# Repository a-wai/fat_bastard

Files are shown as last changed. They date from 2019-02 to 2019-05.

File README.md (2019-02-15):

Copyright 2019, Arnaud Ferraris.

This documentation describes Open Hardware and is licensed under the
CERN OHL v.1.2.

You may redistribute and modify this documentation under the terms of the
CERN OHL v.1.2. (http://ohwr.org/cernohl).This documentation is distributed
WITHOUT ANY EXPRESS OR IMPLIED WARRANTY, INCLUDING OF MERCHANTABILITY, 
SATISFACTORY QUALITY AND FITNESS FOR A PARTICULAR PURPOSE.

Please see the CERN OHL v.1.2 for applicable conditions.

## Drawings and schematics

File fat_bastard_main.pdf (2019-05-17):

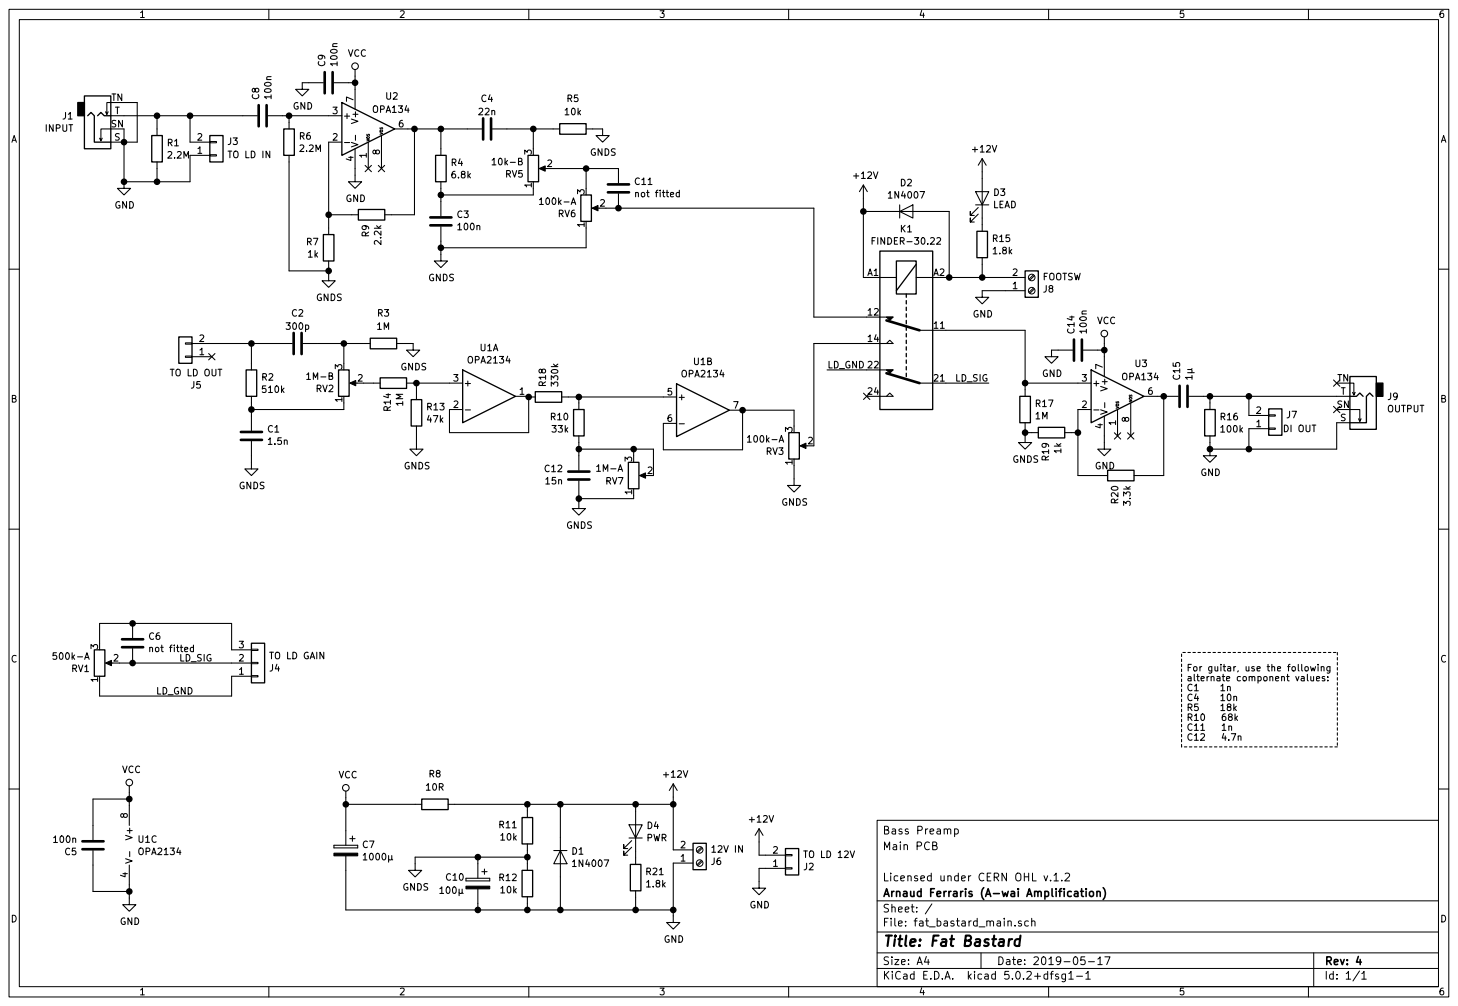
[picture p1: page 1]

For guitar, use the following
alternate component values: C1 1n C4 10n R5 18k R10 68k C11 1n C12 4.7n

Bass Preamp
File: fat_bastard_main.sch Sheet: / Arnaud Ferraris (A-wai Amplification) Licensed under CERN OHL v.1.2 Main PCB

Id: 1/1 Title: Fat Bastard

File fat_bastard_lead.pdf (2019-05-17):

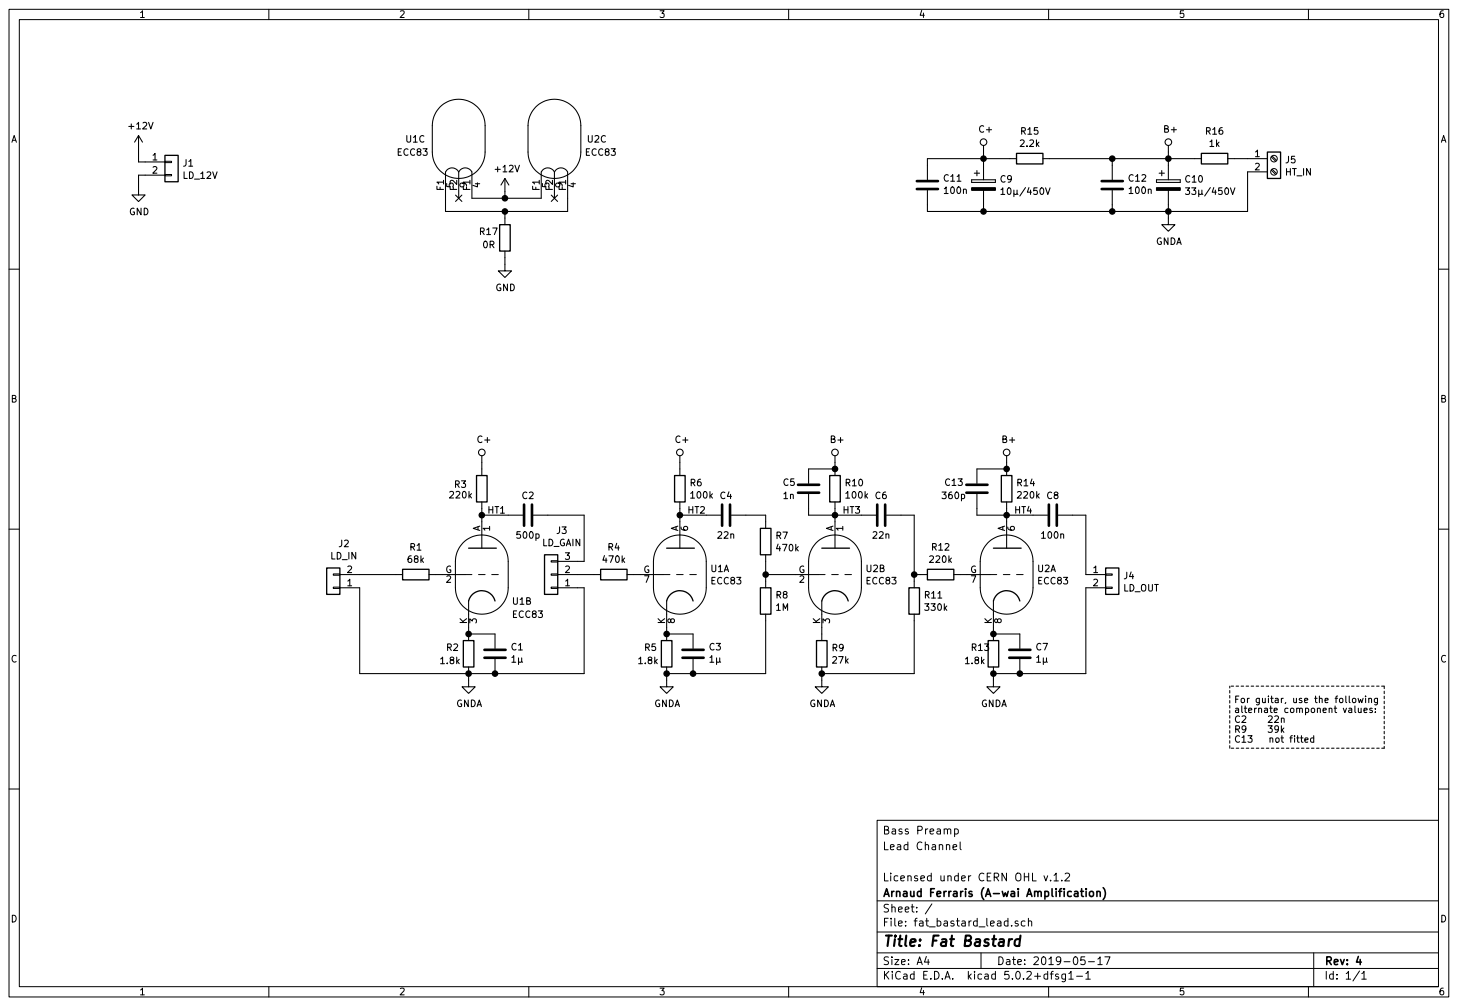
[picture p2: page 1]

Lead Channel Bass Preamp A

For guitar, use the following
alternate component values: C2 22n R9 39k C13 not fitted

File: fat_bastard_lead.sch Sheet: / Arnaud Ferraris (A-wai Amplification) Licensed under CERN OHL v.1.2

Id: 1/1 Title: Fat Bastard

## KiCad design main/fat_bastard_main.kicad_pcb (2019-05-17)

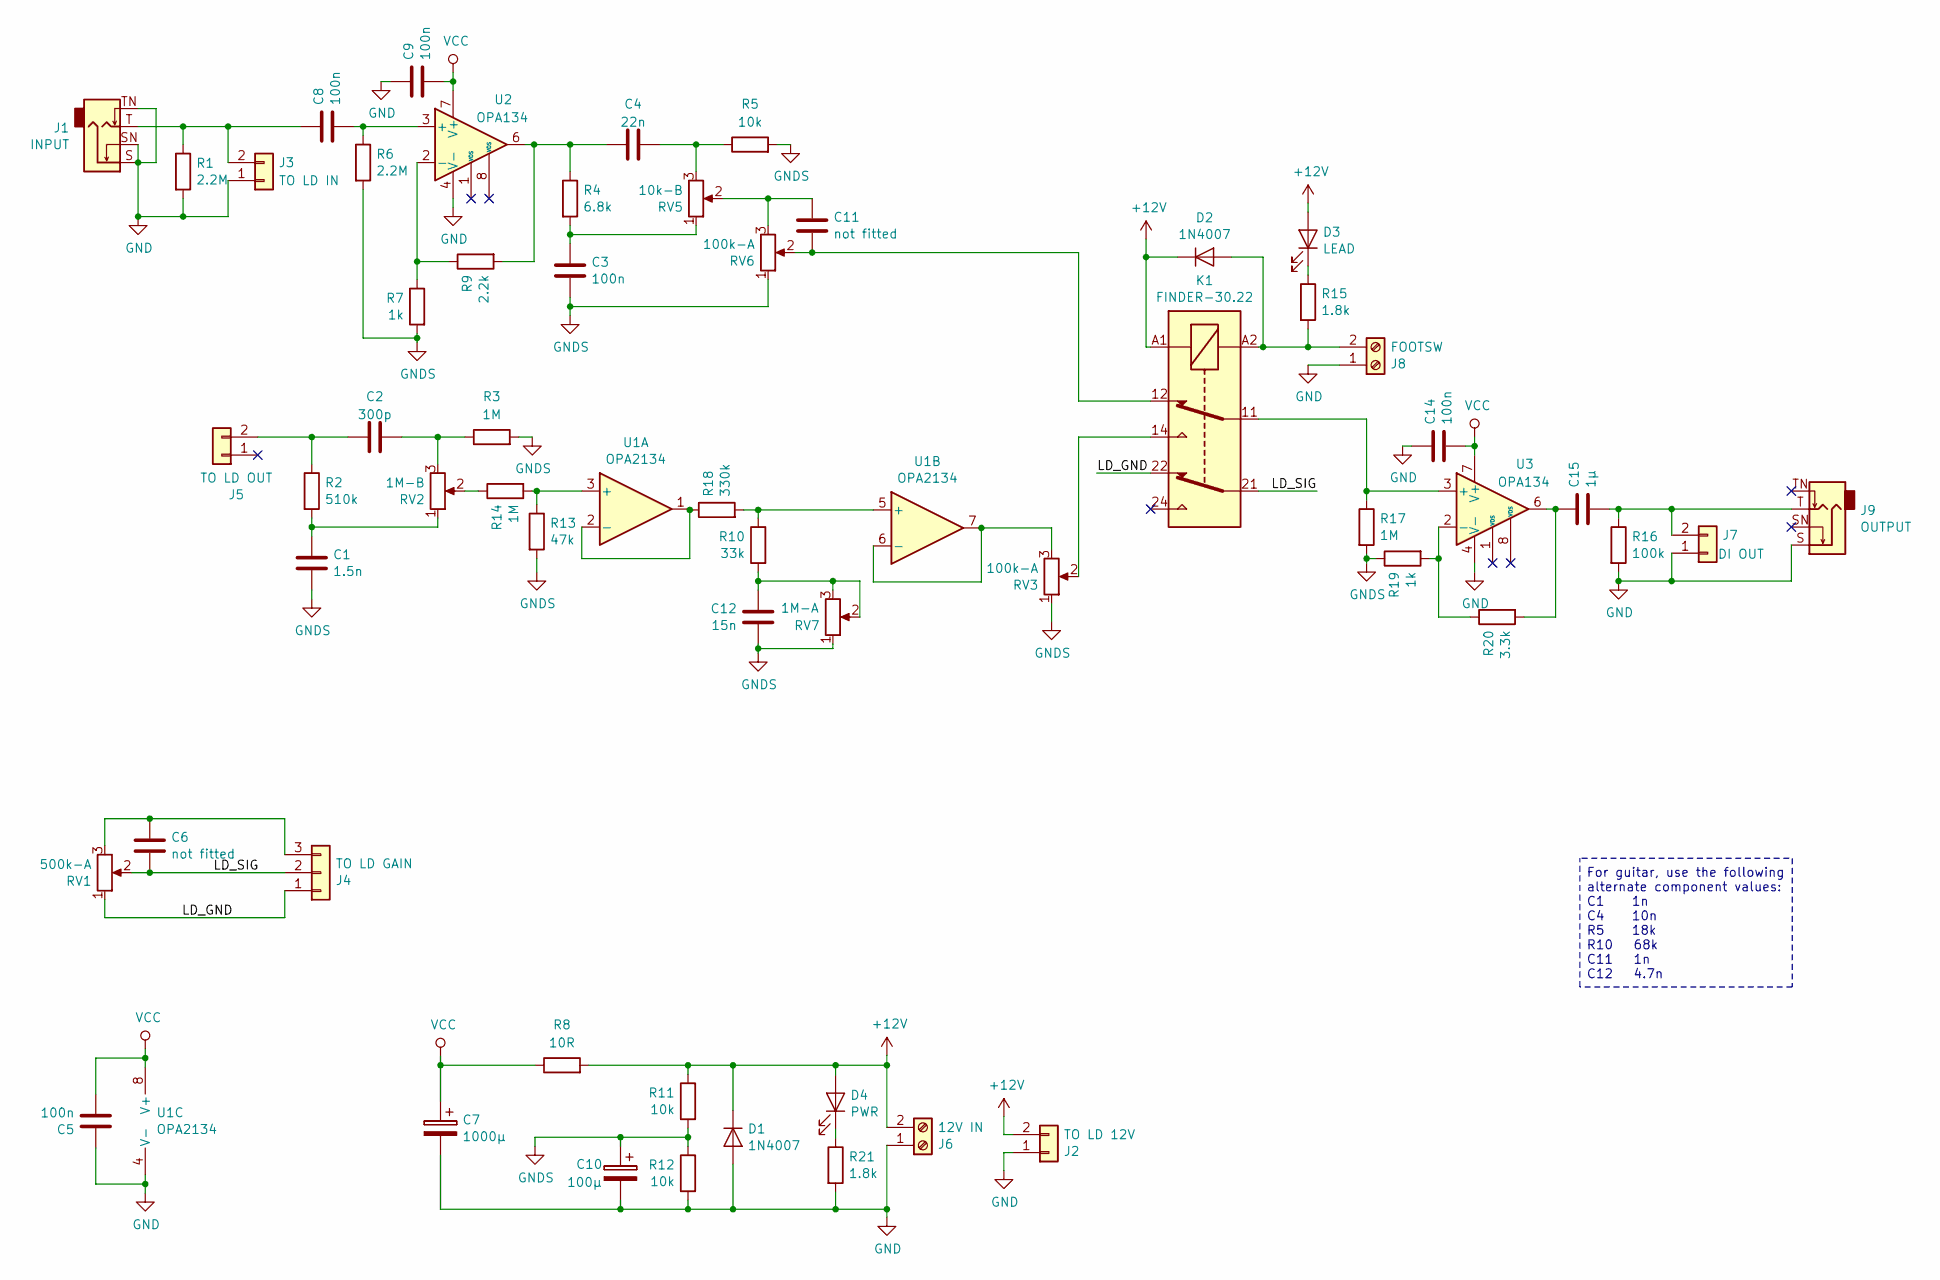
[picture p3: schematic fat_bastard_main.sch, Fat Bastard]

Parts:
C1: 1.5n; C_Rect_L7.2mm_W3.0mm_P5.00mm_FKS2_FKP2_MKS2_MKP2; MPN MKP2
C2: 300p; C_Disc_D10.5mm_W5.0mm_P5.00mm
C3, C5, C8, C9, C14: 100n; C_Rect_L7.2mm_W3.0mm_P5.00mm_FKS2_FKP2_MKS2_MKP2; MPN MKS2D031001A00KSSD
C4: 22n; C_Rect_L7.2mm_W3.0mm_P5.00mm_FKS2_FKP2_MKS2_MKP2; MPN MKS2C022201A00KSSD
C6, C11: not fitted; C_Disc_D10.5mm_W5.0mm_P5.00mm
C7: 1000µ; CP_Radial_D10.0mm_P5.00mm
C10: 100µ; CP_Radial_D8.0mm_P3.80mm; MPN FW
C12: 15n; C_Rect_L7.2mm_W3.0mm_P5.00mm_FKS2_FKP2_MKS2_MKP2; MPN MKS2D021001A00KSSD
C15: 1µ; C_Rect_L7.2mm_W4.5mm_P5.00mm_FKS2_FKP2_MKS2_MKP2; MPN MKS2C041001F00KSSD
D1, D2: 1N4007; D_DO-41_SOD81_P7.62mm_Horizontal
D3: LEAD; LED_D3.0mm_Horizontal_O6.35mm_Z10.0mm
D4: PWR; LED_D3.0mm_Horizontal_O3.81mm_Z2.0mm
J1: INPUT; Jack_3.5mm_Neutrik_NMJ6HCD2_Horizontal; MPN NMJ4HCD2
J2: TO LD 12V; PinHeader_1x02_P2.54mm_Vertical
J3: TO LD IN; PinHeader_1x02_P2.54mm_Vertical
J4: TO LD GAIN; PinHeader_1x03_P2.54mm_Vertical
J5: TO LD OUT; PinHeader_1x02_P2.54mm_Vertical
J6: 12V IN; TerminalBlock_RND_205-00001_1x02_P5.00mm_Horizontal; MPN 691102710002
J7: DI OUT; PinHeader_1x02_P2.54mm_Vertical
J8: FOOTSW; TerminalBlock_RND_205-00001_1x02_P5.00mm_Horizontal; MPN 691102710002
J9: OUTPUT; Jack_3.5mm_Neutrik_NMJ6HCD2_Horizontal; MPN NMJ4HCD2
K1: FINDER-30.22; Relay_DPDT_Finder_30.22; MPN G5V-2
R1, R6: 2.2M; R_Axial_DIN0309_L9.0mm_D3.2mm_P12.70mm_Horizontal
R2: 510k; R_Axial_DIN0309_L9.0mm_D3.2mm_P12.70mm_Horizontal
R3, R14, R17: 1M; R_Axial_DIN0309_L9.0mm_D3.2mm_P12.70mm_Horizontal
R4: 6.8k; R_Axial_DIN0309_L9.0mm_D3.2mm_P12.70mm_Horizontal
R5, R11, R12: 10k; R_Axial_DIN0309_L9.0mm_D3.2mm_P12.70mm_Horizontal
R7, R19: 1k; R_Axial_DIN0309_L9.0mm_D3.2mm_P12.70mm_Horizontal
R8: 10R; R_Axial_DIN0309_L9.0mm_D3.2mm_P12.70mm_Horizontal
R9: 2.2k; R_Axial_DIN0309_L9.0mm_D3.2mm_P12.70mm_Horizontal
R10: 33k; R_Axial_DIN0309_L9.0mm_D3.2mm_P12.70mm_Horizontal
R13: 47k; R_Axial_DIN0309_L9.0mm_D3.2mm_P12.70mm_Horizontal
R15, R21: 1.8k; R_Axial_DIN0309_L9.0mm_D3.2mm_P12.70mm_Horizontal
R16: 100k; R_Axial_DIN0309_L9.0mm_D3.2mm_P12.70mm_Horizontal
R18: 330k; R_Axial_DIN0309_L9.0mm_D3.2mm_P12.70mm_Horizontal
R20: 3.3k; R_Axial_DIN0309_L9.0mm_D3.2mm_P12.70mm_Horizontal
RV1: 500k-A; Potentiometer_Alps_RK163_Single_Horizontal
RV2: 1M-B; Potentiometer_Alps_RK163_Single_Horizontal
RV3, RV6: 100k-A; Potentiometer_Alps_RK163_Single_Horizontal
RV5: 10k-B; Potentiometer_Alps_RK163_Single_Horizontal
RV7: 1M-A; Potentiometer_Alps_RK163_Single_Horizontal
U1: OPA2134; DIP-8_W7.62mm_Socket_LongPads; MPN OPA2134PA
U2, U3: OPA134; DIP-8_W7.62mm_Socket_LongPads; MPN OPA134PA

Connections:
+12V: D1.1 (K), D2.1 (K), D3.2 (A), D4.2 (A), J2.2, J6.2, K1.A1, R8.2, R11.1
/LD_GND: J4.1, K1.22, RV1.1
/LD_SIG: C6.1, J4.2, K1.21, RV1.2
GND: C5.2, C7.2, C9.2, C10.2, C14.2, D1.2 (A), J1.S, J1.SN, J1.TN, J2.1, J3.1, J6.1, J7.1, J8.1, J9.S, R1.2, R12.2, R16.2, R21.2, U1.4 (V-), U2.4 (V-), U3.4 (V-)
GNDS: C1.1, C3.1, C10.1, C12.1, R3.2, R5.2, R6.2, R7.2, R11.2, R12.1, R13.2, R17.2, R19.1, RV3.1, RV6.1, RV7.1
unnamed: C1.2, R2.2, RV2.1
unnamed: C2.1, J5.2, R2.1
unnamed: C2.2, R3.1, RV2.3
unnamed: C3.2, R4.2, RV5.1
unnamed: C4.1, R4.1, R9.2, U2.6
unnamed: C4.2, R5.1, RV5.3
unnamed: C6.2, J4.3, RV1.3
unnamed: C8.1, R6.1, U2.3 (+)
unnamed: C8.2, J1.T, J3.2, R1.1
unnamed: C11.1, K1.12, RV6.2
unnamed: C11.2, RV5.2, RV6.3
unnamed: C12.2, R10.2, RV7.2, RV7.3
unnamed: C15.1, J7.2, J9.T, R16.1
unnamed: C15.2, R20.2, U3.6
unnamed: D2.2 (A), J8.2, K1.A2, R15.2
unnamed: D3.1 (K), R15.1
unnamed: D4.1 (K), R21.1
unnamed: K1.11, R17.1, U3.3 (+)
unnamed: K1.14, RV3.2
unnamed: R7.1, R9.1, U2.2 (-)
unnamed: R10.1, R18.2, U1.5 (+)
unnamed: R13.1, R14.2, U1.3 (+)
unnamed: R14.1, RV2.2
unnamed: R18.1, U1.1, U1.2 (-)
unnamed: R19.2, R20.1, U3.2 (-)
unnamed: RV3.3, U1.6 (-), U1.7
VCC: C5.1, C7.1, C9.1, C14.1, R8.1, U1.8 (V+), U2.7 (V+), U3.7 (V+)

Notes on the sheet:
For guitar, use the following alternate component values: C1 1n C4 10n R5 18k R10 68k C11 1n C12 4.7n

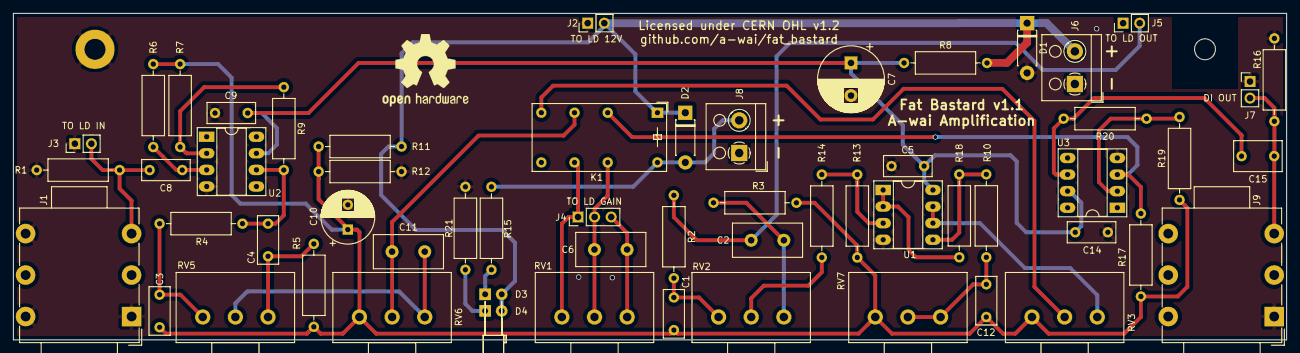
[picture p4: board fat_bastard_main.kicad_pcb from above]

Board: 2 copper layers, 195.0 x 50.0 mm, 60 parts (0 on the bottom side), 32 nets.

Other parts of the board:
DRILL: MountingHole_3.2mm_M3
DRILL#2: MountingHole_3.2mm_M3

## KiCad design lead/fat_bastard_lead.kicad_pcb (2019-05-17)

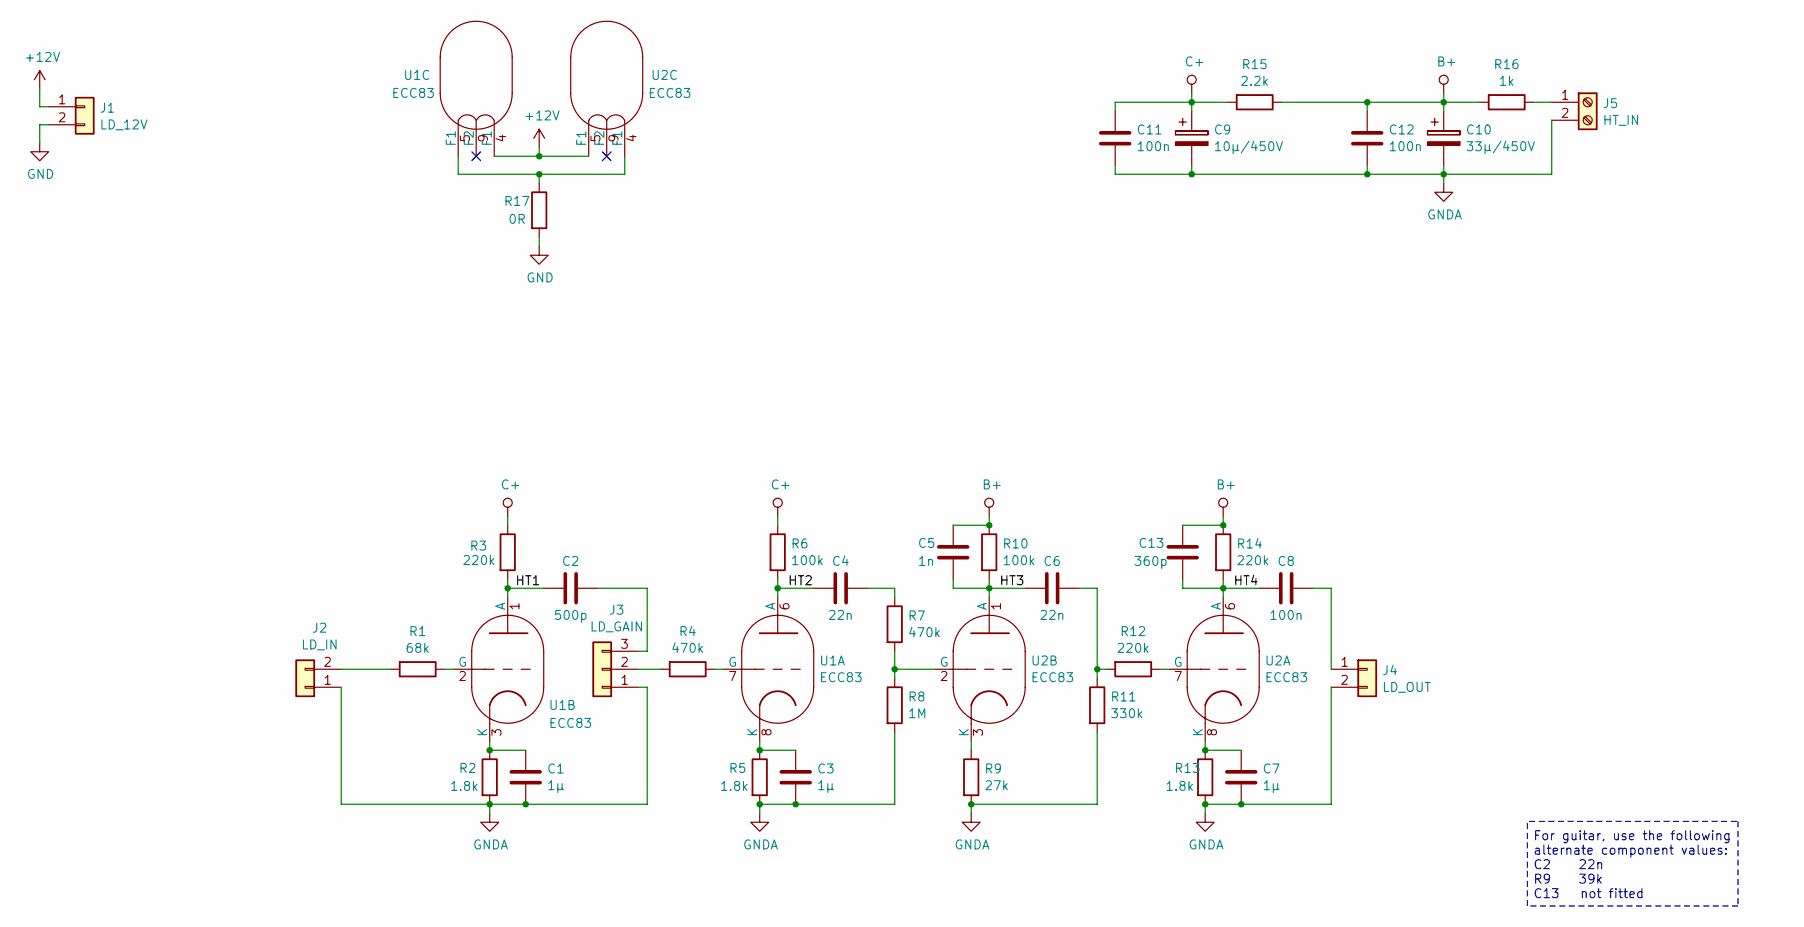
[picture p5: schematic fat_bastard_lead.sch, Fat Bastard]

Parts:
C1, C3, C7: 1µ; C_Rect_L7.2mm_W4.5mm_P5.00mm_FKS2_FKP2_MKS2_MKP2
C2: 500p; C_Disc_D11.0mm_W5.0mm_P5.00mm
C4, C6: 22n; C_Rect_L13.0mm_W4.0mm_P10.00mm_FKS3_FKP3_MKS4
C5: 1n; C_Rect_L13.0mm_W4.0mm_P10.00mm_FKS3_FKP3_MKS4
C8, C11, C12: 100n; C_Rect_L19.0mm_W6.0mm_P15.00mm_MKS4
C9: 10µ/450V; CP_Radial_D13.0mm_P5.00mm
C10: 33µ/450V; CP_Radial_D16.0mm_P7.50mm
C13: 360p; C_Disc_D11.0mm_W5.0mm_P5.00mm
J1: LD_12V; PinHeader_1x02_P2.54mm_Horizontal
J2: LD_IN; PinHeader_1x02_P2.54mm_Vertical
J3: LD_GAIN; PinHeader_1x03_P2.54mm_Vertical
J4: LD_OUT; PinHeader_1x02_P2.54mm_Horizontal
J5: HT_IN; TerminalBlock_RND_205-00001_1x02_P5.00mm_Horizontal
R1: 68k; R_Axial_DIN0309_L9.0mm_D3.2mm_P12.70mm_Horizontal
R2, R5, R13: 1.8k; R_Axial_DIN0309_L9.0mm_D3.2mm_P12.70mm_Horizontal
R3, R12, R14: 220k; R_Axial_DIN0309_L9.0mm_D3.2mm_P12.70mm_Horizontal
R4, R7: 470k; R_Axial_DIN0309_L9.0mm_D3.2mm_P12.70mm_Horizontal
R6, R10: 100k; R_Axial_DIN0309_L9.0mm_D3.2mm_P12.70mm_Horizontal
R8: 1M; R_Axial_DIN0309_L9.0mm_D3.2mm_P12.70mm_Horizontal
R9: 27k; R_Axial_DIN0309_L9.0mm_D3.2mm_P12.70mm_Horizontal
R11: 330k; R_Axial_DIN0309_L9.0mm_D3.2mm_P12.70mm_Horizontal
R15: 2.2k; R_Axial_DIN0309_L9.0mm_D3.2mm_P12.70mm_Horizontal
R16: 1k; R_Axial_DIN0309_L9.0mm_D3.2mm_P12.70mm_Horizontal
R17: 0R; SolderJumper-2_P1.3mm_Bridged2Bar_Pad1.0x1.5mm
U1, U2: ECC83; Valve_Noval-B9A_Belton-VT9-PT_Socket

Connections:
+12V: J1.1, U1.4 (F1), U2.5 (F1)
/HT1: C2.2, R3.2, U1.1 (A)
/HT2: C4.2, R6.2, U1.6 (A)
/HT3: C5.2, C6.2, R10.2, U2.1 (A)
/HT4: C8.2, C13.2, R14.2, U2.6 (A)
B+: C5.1, C10.1, C12.2, C13.1, R10.1, R14.1, R15.1, R16.2
C+: C9.1, C11.2, R3.1, R6.1, R15.2
GND: J1.2, R17.2
GNDA: C1.1, C3.1, C7.1, C9.2, C10.2, C11.1, C12.1, J2.1, J3.1, J4.2, J5.2, R2.2, R5.2, R8.2, R9.2, R11.2, R13.2
unnamed: C1.2, R2.1, U1.3 (K)
unnamed: C2.1, J3.3
unnamed: C3.2, R5.1, U1.8 (K)
unnamed: C4.1, R7.1
unnamed: C6.1, R11.1, R12.2
unnamed: C7.2, R13.1, U2.8 (K)
unnamed: C8.1, J4.1
unnamed: J2.2, R1.2
unnamed: J3.2, R4.2
unnamed: J5.1, R16.1
unnamed: R1.1, U1.2 (G)
unnamed: R4.1, U1.7 (G)
unnamed: R7.2, R8.1, U2.2 (G)
unnamed: R9.1, U2.3 (K)
unnamed: R12.1, U2.7 (G)
unnamed: R17.1, U1.5 (F1), U2.4 (F1)

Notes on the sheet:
For guitar, use the following alternate component values: C2 22n R9 39k C13 not fitted

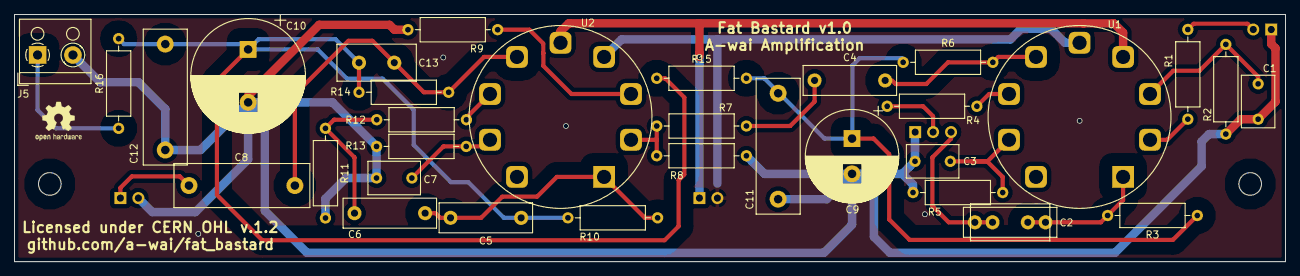
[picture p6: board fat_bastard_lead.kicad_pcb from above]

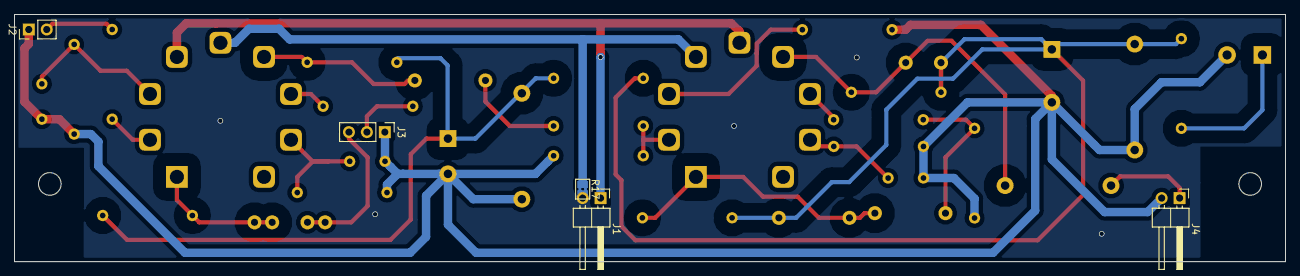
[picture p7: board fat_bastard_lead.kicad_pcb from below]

Board: 2 copper layers, 180.0 x 35.0 mm, 39 parts (5 on the bottom side), 25 nets.

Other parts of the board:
DR1, DR1#2: FIX; MountingHole_3.2mm_M3

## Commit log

2019-02-15 Initial release
    [Fat Bastard.sch]
2019-02-15 Rename file as there will be multiple KiCAD projects/PCBs
    The project will include 2 PCBs: one for the lead channel only, the
    other one for the main circuit. As the files currenly include only the
    lead PCB, rename them to fat_bastard_lead.*
    The main PCB files will be named fat_bastard_main.*
    [fat_bastard_lead.sch]
2019-02-15 Route lead channel PCB
    [fat_bastard_lead.kicad_pcb, fat_bastard_lead.sch]
2019-02-15 Add main PCB schematic
    [fat_bastard_main.sch]
2019-02-15 Move design files to subdirectories
    In order to keep both PCBs files separate, move all design files to
    lead/ and main/ subfolders.
    [fat_bastard_lead.kicad_pcb, fat_bastard_lead.sch, fat_bastard_main.sch]
2019-02-15 Add license (CERN OHL v.1.2)
    [fat_bastard_lead.kicad_pcb, fat_bastard_lead.sch, fat_bastard_main.sch]
2019-02-15 Add PDF rendering of the schematics
2019-02-21 Improve tubes PCB & add tubes 3D models
    Small changes were made to the lead PCB in order to avoid having solders
    touching the main PCB.
    Additionnally, the tubes footprints have been replaced to accomodate
    PCB-mount tube sockets, and 3D models have been added for the tubes in
    order to improve 3D rendering.
    [fat_bastard_lead.kicad_pcb]
2019-02-21 Add exclusion zones for mounting brackets
    In order to avoid possible shortcuts, exclusion zones have been added to
    the back side of the PCB, and a few components have been moved in order
    to prevent unwanted contact.
    [fat_bastard_lead.kicad_pcb]
2019-02-21 [main] First version of the main PCB
    [fat_bastard_main.kicad_pcb, fat_bastard_main.sch]
2019-02-22 [lead] Add small capacitor on last gain stage's anode
    The schematics has too much treble for now, and must be used with the
    Tone setting between 2 and 4/10. Adding this capacitor (300-500p, tune
    to taste) gives a more full-bodied sound, and enables to use the Tone
    control across a broader range.
    [fat_bastard_lead.kicad_pcb, fat_bastard_lead.sch]
2019-02-22 [lead] change footprint for C2
    C2 is currently a 500p capacitor, doing heavy filtering of the low
    frequencies to achieve a "modern" tone. By changing the footprint, it
    can be replaced with a film capacitor (i.e. MKS4) of up to 10nF, giving
    a broader range of possible tones.
    [fat_bastard_lead.kicad_pcb, fat_bastard_lead.sch]
2019-02-28 [main] Attenuate lead channel & improve buffering + final PCB
    Lead channel has a high output level, while the signal level after the
    Depth control is quite low. Therfore, we need to attenuate the lead
    channel before trying to mix in the signal coming from the Depth pot.
    Additionnally, the output buffer is changed to a make-up gain stage.
    With these changes in mind, the PCB design has been completed.
    [fat_bastard_main.kicad_pcb, fat_bastard_main.sch]
2019-02-28 [main-alt] Add alternate main PCB
    The Depth control as implemented on the main PCB has been tested to work
    as expected. However, another implementation might be interesting,
    especially when targetting guitar players. This alternate main PCB
    is therefore designed to test another Depth implementation.
    [fat_bastard_main-alt.kicad_pcb, fat_bastard_main-alt.sch]
2019-03-23 Fix potentiometers orientation
    [fat_bastard_main-alt.kicad_pcb, fat_bastard_main-alt.sch]
2019-03-23 Improve rounting
    [fat_bastard_main-alt.kicad_pcb, fat_bastard_main-alt.sch]
2019-03-23 Make main-alt PCB the only main PCB
    [fat_bastard_main-alt.kicad_pcb, fat_bastard_main-alt.sch, fat_bastard_main.kicad_pcb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]
2019-03-26 Add bright cap, DI out & improve routing
    * Add bright cap on clean channel
    * Add DI out pin header
    * Change connections to improve routing
    * Connect pin 1 of each pin header & terminal block to GND for improved
    consistency
    * Improve overall routing to avoid vias
    [fat_bastard_main.kicad_pcb, fat_bastard_main.sch]
2019-04-15 [main] Fix channel switching
    Due to changing the schematics layout in the previous version, default
    channel is lead and is muted.
    This commit restores the original layout and fixes the corresponding
    traces.
    [fat_bastard_main.kicad_pcb, fat_bastard_main.sch]
2019-05-17 Add alternate component values for guitar
    In its original form, this preamp could very well be used with a guitar,
    providing a rather tight and modern sound.
    This patch adds alternate values, designed for use with guitar,
    resulting in a warmer, fuller, stoner/rock guitar tone.
    [fat_bastard_lead.kicad_pcb, fat_bastard_lead.sch, fat_bastard_main.kicad_pcb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]
2019-10-02 Add Gerber files
    [fat_bastard_lead-B_Cu.gbl, fat_bastard_lead-B_Mask.gbs, fat_bastard_lead-Edge_Cuts.gm1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]
